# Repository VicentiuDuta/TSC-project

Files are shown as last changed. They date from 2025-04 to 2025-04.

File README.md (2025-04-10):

# OpenBook - E-book Reader

## Descriere generala

OpenBook este un dispozitiv de citit carti electronice (e-book reader) conceput pentru a fi ieftin si open-source.

## Diagrama bloc

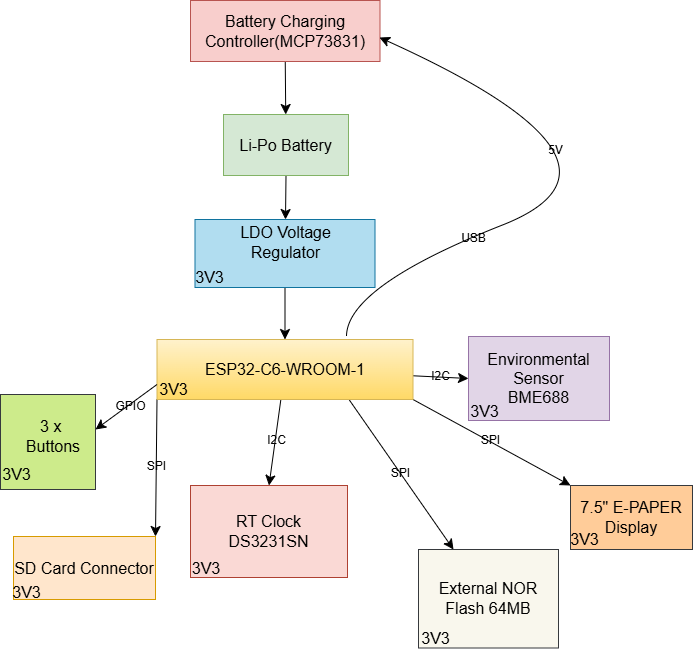
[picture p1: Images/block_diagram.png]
Diagrama bloc


## Bill Of Materials (BOM)
| Componenta | Link | Datasheet |
|---|---|---|
| BD5229G-TR | [Mouser](https://ro.mouser.com/ProductDetail/ROHM-Semiconductor/BD5229G-TR?qs=4kLU8WoGk0vvnhrrYwdszw%3D%3D) | [Datasheet](https://fscdn.rohm.com/en/products/databook/datasheet/ic/power/voltage_detector/bd52xxg-e.pdf)|
| BME688 | [Mouser](https://ro.mouser.com/ProductDetail/Bosch-Sensortec/BME688?qs=IS%252B4QmGtzzqQoVDscqwx3A%3D%3D) | [Datasheet](https://ro.mouser.com/datasheet/2/783/bst_bme688_fl000-2307034.pdf)|
| Bobina | [Mouser](https://ro.mouser.com/ProductDetail/Wurth-Elektronik/744043680?qs=PGXP4M47uW6VkZq%252BkzjrHA%3D%3D) | [Datasheet](https://www.we-online.com/components/products/datasheet/744043680.pdf)|
| Button | [Mouser](https://ro.mouser.com/ProductDetail/CK/KMR221GULCLFS?qs=u2NJ%252B70r0goBXaNk7IrU0Q%3D%3D) |[Datasheet](https://www.ckswitches.com/media/1479/kmr2.pdf)|
| Capacitor 0.1uF / 50V | [Farnell](https://ro.farnell.com/multicomp-pro/mcmlr50v104kx7r/ceramic-capacitor-0-1uf-50v-x7r/dp/1600875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) | [Datasheet](https://www.farnell.com/datasheets/2873577.pdf?_gl=1*x28a2*_gcl_au*MTYwODAzNzc2OC4xNzQzNDM1MjM4)|
| Capacitor 1uF | [Mouser](https://ro.mouser.com/ProductDetail/KEMET/C0402C105K9PACTU?qs=UdQET6xYxVCMExqTDkuPeQ%3D%3D) | [Datasheet](https://ro.mouser.com/datasheet/2/447/KEM_C1006_X5R_SMD-3316465.pdf)|
| Capacitor 1uF / 50V | [Mouser](https://ro.mouser.com/ProductDetail/TDK/C1608X7R1H105K080AB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) | [Datasheet](https://product.tdk.com/system/files/dam/doc/product/capacitor/ceramic/mlcc/catalog/mlcc_commercial_general_en.pdf)|
| Capacitor 4.7uF | [Mouser](https://ro.mouser.com/ProductDetail/KEMET/C0402C475M9PAC7411?qs=cpo3%2FpBou2jRzZxyxJnMGg%3D%3D) | [Datasheet](https://ro.mouser.com/datasheet/2/447/KEM_C1006_X5R_SMD-3316465.pdf)|
| Capacitor 4.7uF / 25V | [Mouser](https://ro.mouser.com/ProductDetail/KYOCERA-AVX/12063C475KAZ2A?qs=%252BdQmOuGyFcG3LdbVp5waMw%3D%3D) | [Datasheet](https://ro.mouser.com/datasheet/2/40/X7RDielectric-2943470.pdf)|
| Capacitor 10uF | [Mouser](https://ro.mouser.com/ProductDetail/KEMET/C0402C106M9PACTU?qs=x4XeXhDQKnp%252Bz0lMlwMC3A%3D%3D) | [Datasheet](https://ro.mouser.com/datasheet/2/447/KEM_C1006_X5R_SMD-3316465.pdf)|
| Capacitor 100nF | [Mouser](https://ro.mouser.com/ProductDetail/KEMET/C0402C104K4RAL?qs=pIZUS6sqCWCaMuP2QVR%2Fog%3D%3D) | [Datasheet](https://ro.mouser.com/datasheet/2/447/KEM_C1018_X7R_SnPb_SMD-3316276.pdf)|
| Capacitor 100uF TANT | [Mouser](https://ro.mouser.com/ProductDetail/KYOCERA-AVX/TAJW107M010RNJ?qs=Wtp%252Bf%2FAeVqIH8v1VxV%252B1Rg%3D%3D) | [Datasheet](https://ro.mouser.com/datasheet/2/40/TAJ-3165264.pdf)|
| Capacitor SUPERCAP | [Mouser](https://ro.mouser.com/ProductDetail/Seiko-Semiconductors/CPH3225A?qs=3etwrb1wR%252BhUOph6lAO7eg%3D%3D) | [Datasheet](https://ro.mouser.com/datasheet/2/360/Seiko_Instruments_MicroBattery_E_20230330_2024Jan_-3561061.pdf)|
| CHG_LED | [CPC](https://cpc.farnell.com/kingbright/kpg-1608zgc/led-smd-0603-grn/dp/SC20796) | [Datasheet](https://www.farnell.com/datasheets/2046349.pdf)|
| DMG2305UX-7 | [Mouser](https://ro.mouser.com/ProductDetail/Diodes-Incorporated/DMG2305UX-7?qs=L1DZKBg7t5F%2FNBHrjfxC%252Bg%3D%3D) | [Datasheet](https://www.diodes.com/assets/Datasheets/DMG2305UX.pdf)|
| DS3231SN# | [Mouser](https://ro.mouser.com/ProductDetail/Analog-Devices-Maxim-Integrated/DS3231SN?qs=1eQvB6Dk1vhUlr8%2FOrV0Fw%3D%3D) | [Datasheet](https://ro.mouser.com/datasheet/2/609/DS3231-3421123.pdf)|
| ESP32-C6-WROOM-1-N8 | [Mouser](https://ro.mouser.com/ProductDetail/Espressif-Systems/ESP32-C6-WROOM-1-N8?qs=8Wlm6%252BaMh8ST02Gmwp74cw%3D%3D) | [Datasheet](https://ro.mouser.com/datasheet/2/891/Espressif_ESP32_C6_WROOM_1__Datasheet_V0_1_PRELIMI-3239987.pdf)|
| FH34SRJ-24S-0.5SH_99_ | [Mouser](https://ro.mouser.com/ProductDetail/Hirose-Connector/FH34SRJ-24S-0.5SH99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) | [Datasheet](https://ro.mouser.com/datasheet/2/185/FH34SRJ_24S_0_5SH_99__CL0580_1255_6_99_2DDrawing_0-1615044.pdf)|
| 112A-TAAR-R03_ATTEND | [LCSC](https://www.lcsc.com/product-detail/SD-Card-Connectors_Attend-Technology-112A-TAAR-R03_C6970445.html) | [Datasheet](https://www.lcsc.com/datasheet/lcsc_datasheet_2411220717_Attend-Technology-112A-TAAR-R03_C6970445.pdf)|
| MAX17048G+T10 | [Mouser](https://ro.mouser.com/ProductDetail/Analog-Devices-Maxim-Integrated/MAX17048G%2bT10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) | [Datasheet](https://ro.mouser.com/datasheet/2/609/MAX17048_MAX17049-3469099.pdf)|
| MBR0530 | [Mouser](https://ro.mouser.com/ProductDetail/onsemi/MBR0530T3G?qs=3JMERSakebpEmdUS6GetdQ%3D%3D) | [Datasheet](https://www.onsemi.com/products/discrete-power-modules/schottky-diodes-schottky-rectifiers/mbr0530t3g)|
| MCP73831 | [Mouser](https://ro.mouser.com/ProductDetail/Microchip-Technology/MCP73831-2ACI-MC?qs=hH%252BOa0VZEiBneYTVdpuVdg%3D%3D) | [Datasheet](https://ro.mouser.com/datasheet/2/268/MCP73831_Family_Data_Sheet_DS20001984H-3441711.pdf)|
| PFMF.050.1 | [Mouser](https://ro.mouser.com/ProductDetail/Schurter/PFMF.050.2?qs=1auRipcfynCums5v1iucSA%3D%3D) | [Datasheet](https://ro.mouser.com/datasheet/2/358/typ_PFMF-1275918.pdf)|
| PGB1010603MR | [Mouser](https://ro.mouser.com/ProductDetail/Littelfuse/PGB1010603MR?qs=gu7KAQ731URLg4GSnNNN7Q%3D%3D) | [Datasheet](https://www.littelfuse.com/assetdocs/pulseguard-esd-suppressors-pgb1-datasheet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)|
| QWIIC_RIGHT_ANGLEA | [Mouser](https://ro.mouser.com/ProductDetail/JST-Commercial/SM04B-SRSS-TBLFSN?qs=cdbOS8ANM9B3FdyA6cNU2A%3D%3D) | [Datasheet](https://ro.mouser.com/datasheet/2/564/eSR_SZ-3476820.pdf)|
| Resistor 0.47 | [Mouser](https://ro.mouser.com/ProductDetail/Vishay-Beyschlag/MCT06030C4700FP500?qs=XsZ9OvPb0dt82KlzjdcMjQ%3D%3D) | [Datasheet](https://www.vishay.com/docs/28705/mcx0x0xpro.pdf)|
| Resistor 2k | [Venkel](https://www.venkel.com/part/CR0402-16W-2002FT) | [Datasheet](https://data.venkel.com/documents/cr-series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.)|
| Resistor 5k1 | [Venkel](https://venkel.com/part/CR0402-10W-5101FT) | [Datasheet](https://data.venkel.com/documents/cr-series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.)|
| Resistor 10K | [DigiKey](https://www.digikey.com/en/products/detail/venkel/CR0402-10W-102JT/12332774) | [Datasheet](https://data.venkel.com/documents/cr-series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.)|
| Resistor 100K | [Venkel](https://venkel.com/part/CR0402-16W-1003FT) | [Datasheet](https://data.venkel.com/documents/cr-series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.)|
| SAMACSYS_PARTS_USB4110-GF-A | [Mouser](https://ro.mouser.com/ProductDetail/GCT/USB4110-GF-A?qs=KUoIvG%2F9IlYiZvIXQjyJeA%3D%3D) | [Datasheet](https://ro.mouser.com/datasheet/2/837/GCT_USB4110_Product_Drawing___20k_cycles-3455479.pdf)|
| SD0805S020S1R0 | [Mouser](https://ro.mouser.com/ProductDetail/KYOCERA-AVX/SD0805S020S1R0?qs=jCA%252BPfw4LHbpkAoSnwrdjw%3D%3D) | [Datasheet](https://ro.mouser.com/datasheet/2/40/schottky-3165252.pdf)|
| SI1308EDL-T1-GE3 | [Mouser](https://ro.mouser.com/ProductDetail/Vishay-Semiconductors/SI1308EDL-T1-GE3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) | [Datasheet](https://www.vishay.com/docs/63399/si1308edl.pdf)|
| USBLC6-2SC6Y | [Mouser](https://ro.mouser.com/ProductDetail/STMicroelectronics/USBLC6-2SC6Y?qs=gNDSiZmRJS%2FOgDexvXkdow%3D%3D) | [Datasheet](https://ro.mouser.com/datasheet/2/389/usblc6_2sc6y-1852505.pdf)|
| W25Q512JVEIQ | [Mouser](https://ro.mouser.com/ProductDetail/Winbond/W25Q512JVEIQ?qs=l7cgNqFNU1jw6svr3at6tA%3D%3D) | [Datasheet](https://ro.mouser.com/datasheet/2/949/Winbond_W25Q512JV_Datasheet-3240039.pdf)|
| XC6220A331MR-G | [Mouser](https://ro.mouser.com/ProductDetail/Torex-Semiconductor/XC6220A331MR-G?qs=AsjdqWjXhJ8ZSWznL1J0gg%3D%3D) | [Datasheet](https://ro.mouser.com/datasheet/2/760/xc6220-3371556.pdf)|

## Descrierea functionalitatii hardware

### Sistem de alimentare si gestionare a energiei

Dispozitivul OpenBook implementeaza un sistem dual de alimentare, functionand atat prin conectorul USB-C cat si prin bateria reincarcabila Li-Po. Modulul MCP73831 gestioneaza procesul de incarcare inteligenta a bateriei, asigurand protectie la supraincarcare si optimizarea ciclurilor de incarcare. Convertorul LDO XC6220A331MR-G stabilizeaza tensiunea la 3.3V pentru toate componentele electronice, asigurand functionarea eficienta a sistemului.

Pentru alimentarea afisajului e-paper, care necesita tensiuni specifice, am proiectat un circuit dedicat bazat pe bobina inductiva 744043680 si diode Schottky pentru generarea si stabilizarea tensiunilor necesare functionarii optime a ecranului.

### Unitatea centrala de procesare

La baza sistemului se afla modulul ESP32-C6-WROOM-1-N8, care integreaza microcontrolerul ESP32-C6 impreuna cu conectivitate wireless WiFi si Bluetooth. Acesta coordoneaza toate operatiunile dispozitivului, de la gestionarea interfetei cu utilizatorul pana la procesarea si afisarea textului. Designul include butoane dedicate pentru reset si boot, facilitand atat utilizarea normala cat si procesele de dezvoltare si depanare.

### Sisteme de conectivitate si interfete

- **Portul USB-C**: Asigura atat alimentarea si incarcarea bateriei cat si transferul de date pentru gestionarea bibliotecii digitale
- **Slotul microSD**: Permite extinderea capacitatii de stocare pentru biblioteci extinse de carti electronice
- **Conectorul FPC cu 24 pini**: Interfata specializata pentru afisajul e-paper de 7.5 inch
- **Conectorul Qwiic/Stemma QT**: Faciliteaza integrarea modulara a senzorilor si perifericelor I2C aditionale

### Subsisteme de stocare si functii auxiliare

- **Memoria flash W25Q512JVEIQ**: Ofera 64MB de spatiu de stocare persistent pentru sistemul de operare si datele utilizatorului
- **Modulul RTC DS3231**: Mentine cronometrarea precisa a timpului real, chiar si cand dispozitivul este oprit, datorita sistemului de backup cu supercapacitor
- **Senzorul ambiental BME688**: Monitorizeaza conditiile de mediu (temperatura, umiditate, presiune atmosferica si calitatea aerului) pentru ajustarea optima a parametrilor de afisare
- **Circuitul integrat MAX17048**: Monitorizeaza cu precizie starea bateriei si ofera utilizatorului informatii despre autonomia ramasa

## Design Log
- Am modificat pozitionarea butoanelor din carcasa pentru a se potrivi cu cele de pe PCB.
- Am aprobat 2 erori DRC de dimenisiune pentru USB, conform enuntului.

## Descrierea pinilor ESP32-C6 utilizati

| Pin ESP32-C6 | Functie | Descriere |
|---|---|---|
| IO0 | INT_RTC | Semnal de intrerupere de la RTC |
| IO1 | 32KHZ | Semnal de ceas de la RTC |
| IO2 | MISO | Comunicatie SPI cu cardul SD|
| IO3 | EPD_BUSY | Semnal ocupat de la e-paper |
| IO4, IO5 | SS_SD, EPD_DC | Selectie card SD si control date/comanda e-paper |
| IO6, IO7 | SCK, MOSI | Clock SPI si date de iesire |
| IO8 | GPIO8 | Pin de uz general |
| IO9 | IO/BOOT | Buton de boot |
| IO10, IO11 | EPD_CS, FLASH_CS | Selectie chip pentru display si memoria flash |
| IO12, IO13 | USB_D-, USB_D+ | Comunicatii USB |
| IO15 | IO/CHANGE | Buton de schimbare pagina |
| IO16 | TX | Transmitere seriala (UART) |
| IO17 | RX | Receptie seriala (UART) |
| IO18 | RTC_RST | Reset pentru RTC |
| IO19 | I2C_PW | Control alimentare pentru perifericele I2C |
| IO20 | EPD_3V3_C | Control alimentare pentru display |
| IO21, IO22 | SDA, SCL | Comunicatii I2C |
| IO23 | EPD_RST | Reset pentru display |
| EN | RESET | Semnal de reset pentru ESP32 |

## Imagini:
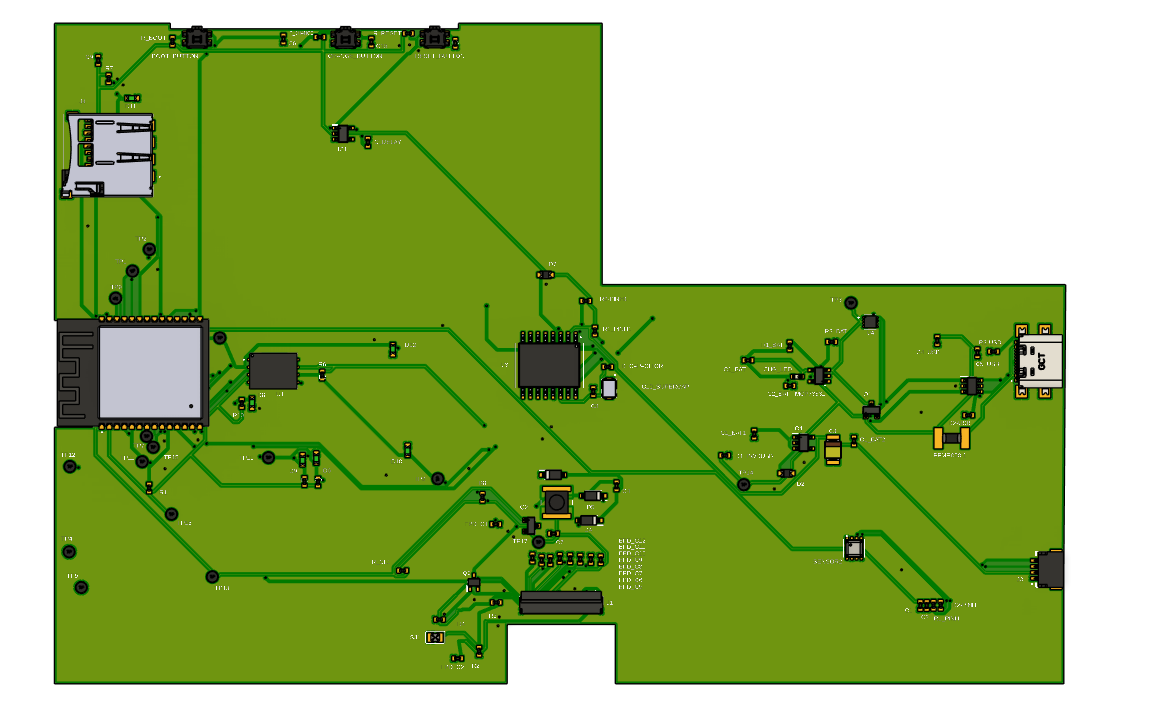
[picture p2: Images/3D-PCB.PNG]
PCB 3D

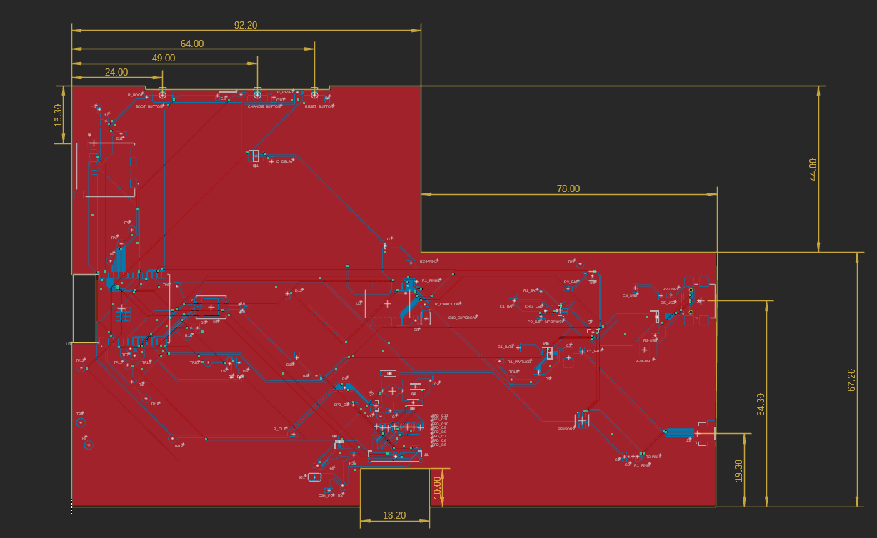
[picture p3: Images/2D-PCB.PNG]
PCB 2D


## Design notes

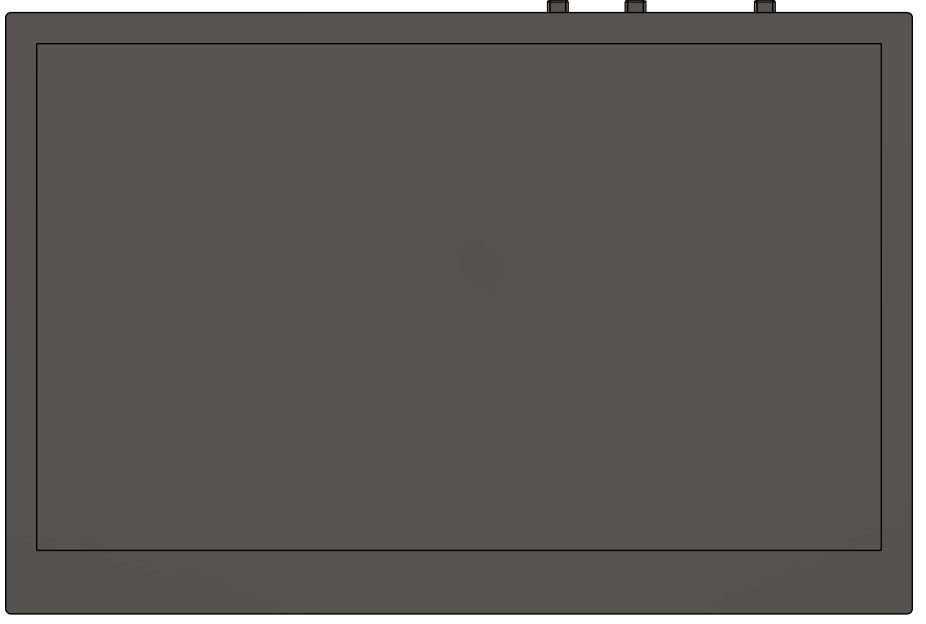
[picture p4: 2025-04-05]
Images/3D-Front.PNG

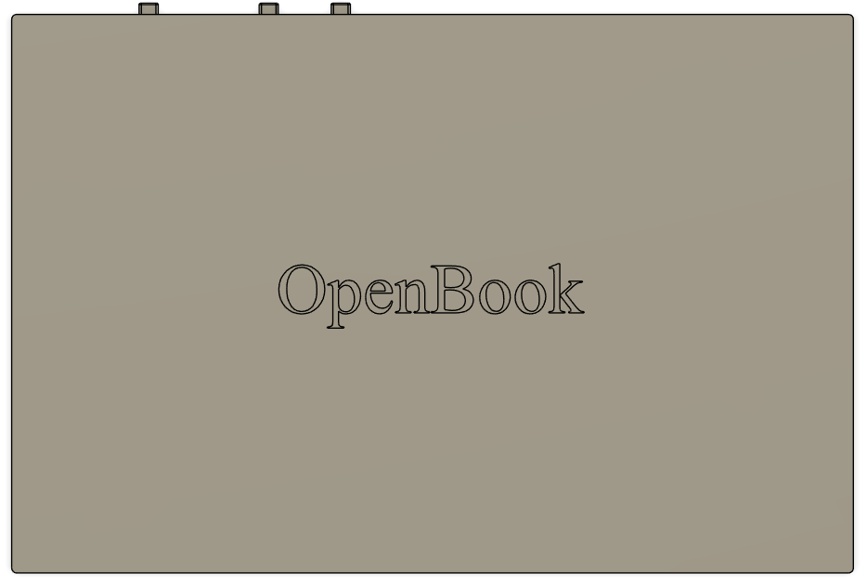
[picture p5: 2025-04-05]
Images/3D-Back.PNG

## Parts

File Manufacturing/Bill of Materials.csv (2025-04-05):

Qty | Value | Device | Package | Parts | Description | ARROW_PART_NUMBER | ARROW_PRICE-STOCK | AVAILABILITY | CENTROID_NOT_SPECIFIED | CHECK_PRICES | COPYRIGHT | DATASHEET | DESCRIPTION | DIGIKEY_DESCRIPTION | DIGIKEY_PART_NUMBER | HEIGHT | LEAD_FREE | MANUFACTURER_NAME | MANUFACTURER_PART_NUMBER | MF | MFR_NAME | MOUSER_PART_NUMBER | MOUSER_PRICE-STOCK | MOUSER_TESTING_PART_NUMBER | MOUSER_TESTING_PRICE-STOCK | MP | MPN | PACKAGE | POPULARITY | PREFIX | PRICE | PROD_ID | PURCHASE-URL | ROHS | SNAPEDA_LINK | SPICEMODEL | SPICEPREFIX | TEMPERATURE_RANGE_HIGH | TEMPERATURE_RANGE_LOW | TP_SIGNAL_NAME | VALUE
1 |  | ADAFRUIT_LEDCHIP-LED0603 | ADAFRUIT_CHIP-LED0603 | CHG_LED | LED
2 |  | ESP32_WROVER_EAGLE-LTSPICE_RR0402 | ESP32_WROVER_EAGLE-LTSPICE_R0402 | R1, R_CHANGE | RESISTOR, European symbol |  |  |  |  |  |  |  |  |  |  |  |  |  |  |  |  |  |  |  |  |  |  |  |  |  |  |  |  |  |  | NONE | R
1 |  | SJ | SJ | SJ1 | SMD solder JUMPER |  |  |  |  |  |  |  |  |  |  |  |  |  |  |  |  |  |  |  |  |  |  |  | 3
1 | 0.1uF/50V | EAGLE-LTSPICE_CC0402 | EAGLE-LTSPICE_C0402 | EPD_C5 | CAPACITOR, European symbol |  |  |  |  |  |  |  |  |  |  |  |  |  |  |  |  |  |  |  |  |  |  |  |  |  |  |  |  |  |  | NONE | C
1 | 0.47 | ESP32_WROVER_EAGLE-LTSPICE_RR0402 | ESP32_WROVER_EAGLE-LTSPICE_R0402 | R3 | RESISTOR, European symbol |  |  |  |  |  |  |  |  |  |  |  |  |  |  |  |  |  |  |  |  |  |  |  |  |  |  |  |  |  |  | NONE | R
1 | 100K | ESP32_WROVER_EAGLE-LTSPICE_RR0402 | ESP32_WROVER_EAGLE-LTSPICE_R0402 | R1_PWRUSB | RESISTOR, European symbol |  |  |  |  |  |  |  |  |  |  |  |  |  |  |  |  |  |  |  |  |  |  |  |  |  |  |  |  |  |  | NONE | R
8 | 100nF | EAGLE-LTSPICE_CC0402 | EAGLE-LTSPICE_C0402 | C1, C2, C4_USB, C6, C8, C9, C10, C_DELAY | CAPACITOR, European symbol |  |  |  |  |  |  |  |  |  |  |  |  |  |  |  |  |  |  |  |  |  |  |  |  |  |  |  |  |  |  | NONE | C
1 | 100uF TANT | RCL_CPOL-EUCT3528 | RCL_CT3528 | C3 | POLARIZED CAPACITOR, European symbol |  |  |  |  |  |  |  |  |  |  |  |  |  |  |  |  |  |  |  |  |  |  |  | 0 |  |  |  |  |  |  |  | C
13 | 10K | ESP32_WROVER_EAGLE-LTSPICE_RR0402 | ESP32_WROVER_EAGLE-LTSPICE_R0402 | R1_PINH, R1_PINH1, R2-PINH, R2-PINH1, R5, R6, R7, R8, R9, R10, R_BOOT, R_CL1, R_RESET | RESISTOR, European symbol |  |  |  |  |  |  |  |  |  |  |  |  |  |  |  |  |  |  |  |  |  |  |  |  |  |  |  |  |  |  | NONE | R
1 | 10k | ESP32_WROVER_EAGLE-LTSPICE_RR0402 | ESP32_WROVER_EAGLE-LTSPICE_R0402 | R4 | RESISTOR, European symbol |  |  |  |  |  |  |  |  |  |  |  |  |  |  |  |  |  |  |  |  |  |  |  |  |  |  |  |  |  |  | NONE | R
1 | 10uF | EAGLE-LTSPICE_CC0402 | EAGLE-LTSPICE_C0402 | C7 | CAPACITOR, European symbol |  |  |  |  |  |  |  |  |  |  |  |  |  |  |  |  |  |  |  |  |  |  |  |  |  |  |  |  |  |  | NONE | C
1 | 112A-TAAR-R03_ATTEND | 112A-TAAR-R03_ATTEND | 112ATAARR03ATTEND | J4 | Micro SD Card Socket, Push-Push Type, Top Mount, SMT, H=1.83mm, 10u |  |  |  |  |  |  |  | Micro SD Card Socket | Push-Push Type | Top Mount | SMT | H=1.83mm | 10u |  |  | 1.9mm |  | ATTEND | 112A-TAAR-R03 ATTEND
1 | 15 | ESP32_WROVER_EAGLE-LTSPICE_RR0402 | ESP32_WROVER_EAGLE-LTSPICE_R0402 | R_CAPACITOR | RESISTOR, European symbol |  |  |  |  |  |  |  |  |  |  |  |  |  |  |  |  |  |  |  |  |  |  |  |  |  |  |  |  |  |  | NONE | R
1 | 1uF | EAGLE-LTSPICE_CC0402 | EAGLE-LTSPICE_C0402 | C5 | CAPACITOR, European symbol |  |  |  |  |  |  |  |  |  |  |  |  |  |  |  |  |  |  |  |  |  |  |  |  |  |  |  |  |  |  | NONE | C
9 | 1uF/50V | EAGLE-LTSPICE_CC0402 | EAGLE-LTSPICE_C0402 | EPD_C1, EPD_C2, EPD_C6, EPD_C7, EPD_C8, EPD_C9, EPD_C10, EPD_C11, EPD_C12 | CAPACITOR, European symbol |  |  |  |  |  |  |  |  |  |  |  |  |  |  |  |  |  |  |  |  |  |  |  |  |  |  |  |  |  |  | NONE | C
1 | 2.2 | ESP32_WROVER_EAGLE-LTSPICE_RR0402 | ESP32_WROVER_EAGLE-LTSPICE_R0402 | R2 | RESISTOR, European symbol |  |  |  |  |  |  |  |  |  |  |  |  |  |  |  |  |  |  |  |  |  |  |  |  |  |  |  |  |  |  | NONE | R
1 | 200 | ESP32_WROVER_EAGLE-LTSPICE_RR0402 | ESP32_WROVER_EAGLE-LTSPICE_R0402 | R1_BAT | RESISTOR, European symbol |  |  |  |  |  |  |  |  |  |  |  |  |  |  |  |  |  |  |  |  |  |  |  |  |  |  |  |  |  |  | NONE | R
2 | 20V/4.2A/52mO/1.4W | ESP32_WROVER_SPARKFUN-DISCRETESEMI_MOSFET_PCH-DMG2305UX-7 | ESP32_WROVER_SPARKFUN-DISCRETESEMI_SOT23-3 | Q1, Q2 | P-channel MOSFETs |  |  |  |  |  |  |  |  |  |  |  |  |  |  |  |  |  |  |  |  |  |  |  |  |  |  | TRAN-14388 |  |  |  |  |  |  |  |  | 20V/4.2A/52mO/1.4W
1 | 2K | ESP32_WROVER_EAGLE-LTSPICE_RR0402 | ESP32_WROVER_EAGLE-LTSPICE_R0402 | R2_BAT | RESISTOR, European symbol |  |  |  |  |  |  |  |  |  |  |  |  |  |  |  |  |  |  |  |  |  |  |  |  |  |  |  |  |  |  | NONE | R
1 | 4.7Uf | EAGLE-LTSPICE_CC0402 | EAGLE-LTSPICE_C0402 | C1_BAT | CAPACITOR, European symbol |  |  |  |  |  |  |  |  |  |  |  |  |  |  |  |  |  |  |  |  |  |  |  |  |  |  |  |  |  |  | NONE | C
4 | 4.7uF | EAGLE-LTSPICE_CC0402 | EAGLE-LTSPICE_C0402 | C1_BAT1, C1_BAT2, C2_BAT, C5_USB | CAPACITOR, European symbol |  |  |  |  |  |  |  |  |  |  |  |  |  |  |  |  |  |  |  |  |  |  |  |  |  |  |  |  |  |  | NONE | C
1 | 4.7uF/25V | EAGLE-LTSPICE_CC0402 | EAGLE-LTSPICE_C0402 | C4 | CAPACITOR, European symbol |  |  |  |  |  |  |  |  |  |  |  |  |  |  |  |  |  |  |  |  |  |  |  |  |  |  |  |  |  |  | NONE | C
2 | 5K1 | ESP32_WROVER_EAGLE-LTSPICE_RR0402 | ESP32_WROVER_EAGLE-LTSPICE_R0402 | R2-USB, R2-USB1 | RESISTOR, European symbol |  |  |  |  |  |  |  |  |  |  |  |  |  |  |  |  |  |  |  |  |  |  |  |  |  |  |  |  |  |  | NONE | R
1 | 744043680IND_4828-WE-TPC_WRE | 744043680IND_4828-WE-TPC_WRE | IND_4828-WE-TPC_WRE | L1 |  |  |  |  |  |  | Copyright (C) 2024 Ultra Librarian. All rights reserved. |  |  |  |  |  |  |  | 744043680 |  | Wurth Electronics
1 | BD5229G-TR | BD5229G-TR | SOT95P280X125-5N | IC1 | Voltage Detector with Adjustable Delay Time: CMOS processes are utilized to develop high precision, low current consumption CMOS reset ICs that allow arbitrary setting of the delay time. The extensive lineup includes both Nch Open Drain and CMOS output types in a wide range of detection voltages (from 2.3V to 6.0V, in 0.1V steps), enabling selection of the ideal solution based on customer requirements. In addition, the entire series is of course both lead-free and RoHS-compliant. |  |  |  |  |  |  |  | Voltage Detector with Adjustable Delay Time: CMOS processes are utilized to develop high precision | low current consumption CMOS reset ICs that allow arbitrary setting of the delay time. The extensive lineup includes both Nch Open Drain and CMOS output types in a wide range of detection voltages (from 2.3V to 6.0V | in 0.1V steps) | enabling selection of the ideal solution based on customer requirements. In addition | the entire series is of course both lead-free and RoHS-compliant. |  |  | 1.25mm |  | ROHM Semiconductor | BD5229G-TR |  |  | 755-BD5229G-TR | https://www.mouser.co.uk/ProductDetail/ROHM-Semiconductor/BD5229G-TR?qs=4kLU8WoGk0vvnhrrYwdszw%3D%3D
3 | BUTTON_CUSYOMV1 | BUTTON_CUSYOMV1 | MYBUTTON | BOOT_BUTTON, CHANGE_BUTTON, RESET_BUTTON
1 | CPH3225A | CPH3225A | CAPCP3225X100N | C10_SUPERCAP | Cap 0.011F 3.3V 1210 Flat Check availability |  |  | Not in stock |  | https://www.snapeda.com/parts/CPH3225A/Seiko+Instruments/view-part/?ref=eda |  |  | 11 mF (EDLC) Supercapacitor 3.3 V 1210 (3225 Metric) - - |  |  |  |  |  |  | Seiko Instruments |  |  |  |  |  | CPH3225A |  | 1210 Seiko |  |  | None |  | https://www.snapeda.com/api/url_track_click_mouser/?unipart_id=562593&manufacturer=Seiko Instruments&part_name=CPH3225A&search_term=None |  | https://www.snapeda.com/parts/CPH3225A/Seiko+Instruments/view-part/?ref=snap
1 | DS3231SN# | DS3231SN# | SOIC127P1032X265-16N | U3 | Real Time Clock Serial 16-Pin SOIC W T/R Check availability |  |  | In Stock |  | https://www.snapeda.com/parts/DS3231SN%23/Analog+Devices/view-part/?ref=eda |  |  | Extremely Accurate I²C-Integrated RTC/TCXO/Crystal |  |  |  |  |  |  | Analog Devices |  |  |  |  |  | DS3231SN# |  | SOIC-16 Maxim |  |  | None |  | https://www.snapeda.com/api/url_track_click_mouser/?unipart_id=99048&manufacturer=Analog Devices&part_name=DS3231SN#&search_term=None |  | https://www.snapeda.com/parts/DS3231SN%23/Analog+Devices/view-part/?ref=snap
1 | ESP32-C6-WROOM-1-N8 | ESP32-C6-WROOM-1-N8 | XCVR_ESP32-C6-WROOM-1-N8 | U2 | Check availability |  |  | In Stock |  | https://www.snapeda.com/parts/ESP32-C6-WROOM-1-N8/Espressif+Systems/view-part/?ref=eda |  |  | Multiprotocol Modules ESP32-C6 module | Wi-Fi 6 in 2.4 GHz band | Bluetooth 5 | Zigbee 3.0 and Thread. ESP34-WROOM Compatible - ENGINEERING SAMPLE |  |  |  |  |  |  | Espressif Systems |  |  |  |  |  | ESP32-C6-WROOM-1-N8 |  | None |  |  | None |  |  |  | https://www.snapeda.com/parts/ESP32-C6-WROOM-1-N8/Espressif+Systems/view-part/?ref=snap
1 | ESP32C6_VARISTORCN1812 | ESP32C6_VARISTORCN1812 | ESP32C6_VARISTOR_CT/CN1812 | PFMF.050.1 | VARISTOR |  |  |  |  |  |  |  |  |  |  |  |  |  |  |  |  |  |  |  |  |  |  |  | 0
2 | ESP32_WROVER_AVX---SD0805S020S1R0_AVX_SD0805S020S1R0_0_0AVX_SD0805S020S1R0_0_0 | ESP32_WROVER_AVX---SD0805S020S1R0_AVX_SD0805S020S1R0_0_0AVX_SD0805S020S1R0_0_0 | ESP32_WROVER_AVX---SD0805S020S1R0_AVX_SD0805S020S1R0_0 | D2, D7 | Schottky Barrier Rectifier Diode |  |  |  | No |  |  | http://datasheets.avx.com/schottky.pdf |  | DIODE SCHOTTKY 20V 1A 0805 | 478-7800-1-ND |  | yes |  |  | AVX |  | 581-SD0805S020S1R0 |  |  |  |  |  | 0805 (2012 metric) |  | D |  |  |  | yes |  |  |  | +125°C | -55°C
1 | ESP32_WROVER_BME680_BME680 | ESP32_WROVER_BME680_BME680 | ESP32_WROVER_BME680_PSON80P300X300X100-8N | SENSOR2 | Integrated Environmental Unit |  |  | Unavailable |  |  |  |  | Integrated Environmental Unit |  |  |  |  |  |  | Bosch Sensortec |  |  |  |  |  | BME680 |  | LGA-8 Bosch Tools |  |  | None
1 | ESP32_WROVER_SPARKFUN-IC-POWER_MCP73831 | ESP32_WROVER_SPARKFUN-IC-POWER_MCP73831 | ESP32_WROVER_SPARKFUN-IC-POWER_SOT23-5 | MCP73831 | MCP73831T Li-Ion, Li-Pol Controller |  |  |  |  |  |  |  |  |  |  |  |  |  |  |  |  |  |  |  |  |  |  |  |  |  |  | IC-09995
1 | FH34SRJ-24S-0.5SH_99_ | FH34SRJ-24S-0.5SH_99_ | FH34SRJ24S05SH99 | J1 | (0.50mm) Surface Mount, Right Angle |  |  |  |  |  |  |  | 24 Position FFC | FPC Connector Contacts | (0.50mm) Surface Mount | Right Angle |  |  | 1.1mm |  | Hirose | FH34SRJ-24S-0.5SH(99) |  |  | 798-FH34SRJ24S05SH99 | https://www.mouser.co.uk/ProductDetail/Hirose-Connector/FH34SRJ-24S-0.5SH99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
1 | MAX17048G+T10 | MAX17048G+T10 | SON50P200X200X80-9N | U4 | Check availability |  |  | In Stock |  | https://www.snapeda.com/parts/MAX17048G+T10/Analog+Devices/view-part/?ref=eda |  |  | 3µA 1-Cell/2-Cell Fuel Gauge with ModelGauge |  |  |  |  |  |  | Analog Devices |  |  |  |  |  | MAX17048G+T10 |  | TDFN-8 Maxim |  |  | None |  | https://www.snapeda.com/api/url_track_click_mouser/?unipart_id=329239&manufacturer=Analog Devices&part_name=MAX17048G+T10&search_term=None |  | https://www.snapeda.com/parts/MAX17048G+T10/Analog+Devices/view-part/?ref=snap
3 | MBR0530 | MBR0530 | SOD3716X135N | D3, D4, D5 | ON SEMICONDUCTOR - MBR0530 - DIODE, SCHOTTKY, 0.5A, 30V, SOD-123 |  |  | In Stock |  | https://www.snapeda.com/parts/MBR0530/Onsemi/view-part/?ref=eda |  |  | Diode Schottky 30 V 500mA Surface Mount SOD-123 |  |  |  |  |  |  | ON Semiconductor |  |  |  |  |  | MBR0530 |  | SOD-123-2 ON Semiconductor |  |  | None |  | https://www.snapeda.com/api/url_track_click_mouser/?unipart_id=179458&manufacturer=ON Semiconductor&part_name=MBR0530&search_term=None |  | https://www.snapeda.com/parts/MBR0530/Onsemi/view-part/?ref=snap
6 | PGB1010603MR | PGB1010603MR | DIOC1608X36N | D6, D8, D9, D10, D11, D12 | Check availability |  |  | In Stock |  | https://www.snapeda.com/parts/PGB1010603MR/Littelfuse/view-part/?ref=eda |  |  | 150V (Typ) Clamp - Ipp Tvs Diode Surface Mount 0603 (1608 Metric) |  |  |  |  |  |  | Littelfuse Inc. |  |  |  |  |  | PGB1010603MR |  | 0603 Littelfuse Inc. |  |  | None |  | https://www.snapeda.com/api/url_track_click_mouser/?unipart_id=5659453&manufacturer=Littelfuse Inc.&part_name=PGB1010603MR&search_term=None |  | https://www.snapeda.com/parts/PGB1010603MR/Littelfuse/view-part/?ref=snap
1 | QWIIC_RIGHT_ANGLE | QWIIC_CONNECTORJS-1MM | JST04_1MM_RA | J3 | SparkFun I2C Standard Qwiic Connector |  |  |  |  |  |  |  |  |  |  |  |  |  |  |  |  |  |  |  |  |  |  |  |  |  |  | CONN-13694 |  |  |  |  |  |  |  |  | QWIIC_RIGHT_ANGLE
1 | SAMACSYS_PARTS_USB4110-GF-A | SAMACSYS_PARTS_USB4110-GF-A | SAMACSYS_PARTS_USB4110GFA | J2 | CONN USB 2.0 TYPE-C R/A SMT |  |  |  |  |  |  |  | CONN USB 2.0 TYPE-C R/A SMT |  |  | 3.26mm |  | GCT (GLOBAL CONNECTOR TECHNOLOGY) | USB4110-GF-A |  |  | 640-USB4110-GF-A | https://www.mouser.co.uk/ProductDetail/GCT/USB4110-GF-A?qs=KUoIvG%2F9IlYiZvIXQjyJeA%3D%3D
1 | SI1308EDL-T1-GE3 | SI1308EDL-T1-GE3 | SOT65P210X110-3N | Q3 | MOSFET N-Ch 30V 1.5A TrenchFET SC70 Vishay Si1308EDL-T1-GE3 N-channel MOSFET Transistor, 1.5 A, 30 V, 3-Pin SC-70 |  |  | In Stock |  | https://www.snapeda.com/parts/SI1308EDL-T1-GE3/Vishay+Siliconix/view-part/?ref=eda |  |  | Si1308EDL-T1-GE3 N-channel MOSFET Transistor | 1.5 A | 30 V | 3-Pin SC-70 | Siliconix / Vishay SI1308EDL-T1-GE3 |  |  |  |  |  |  | Vishay Siliconix |  |  |  |  |  | SI1308EDL-T1-GE3 |  | SOT-323 Vishay Semiconductor |  |  | None |  | https://www.snapeda.com/api/url_track_click_mouser/?unipart_id=274603&manufacturer=Vishay Siliconix&part_name=SI1308EDL-T1-GE3&search_term=None |  | https://www.snapeda.com/parts/SI1308EDL-T1-GE3/Vishay+Siliconix/view-part/?ref=snap
17 | TPTP20R | TPTP20R | TP20R | TP1, TP2, TP3, TP4, TP5, TP6, TP7, TP8, TP9, TP10, TP11, TP12, TP13, TP14, TP15, TP16, TP17 | Test pad |  |  |  |  |  |  |  |  |  |  |  |  |  |  |  |  |  |  |  |  |  |  |  | 2
1 | USBLC6-2SC6Y | USBLC6-2SC6Y | SOT95P280X145-6N | D1 | Low Cap. ESD Protection Auto SOT-23-6 STMicroelectronics USBLC6-2SC6Y, Dual Uni-Directional TVS Diode Array, 6-Pin SOT-23 |  |  | In Stock |  | https://www.snapeda.com/parts/USBLC6-2SC6Y/STMicroelectronics/view-part/?ref=eda |  |  | 17V Clamp 5A (8/20µs) Ipp Tvs Diode Surface Mount SOT-23-6 |  |  |  |  |  |  | STMicroelectronics |  |  |  |  |  | USBLC6-2SC6Y |  | SOT-23-6 STMicroelectronics |  |  | None |  |  |  | https://www.snapeda.com/parts/USBLC6-2SC6Y/STMicroelectronics/view-part/?ref=snap
1 | W25Q512JVEIQ | W25Q512JVEIQ | SON127P600X800X80-9N | U1 | Check availability |  |  | In Stock |  | https://www.snapeda.com/parts/W25Q512JVEIQ/Winbond+Electronics/view-part/?ref=eda |  |  | FLASH - NOR Memory IC 512Mb (64M x 8) SPI - Quad I/O 133 MHz 8-WSON (8x6) |  |  |  |  |  |  | Winbond Electronics |  |  |  |  |  | W25Q512JVEIQ |  | Package |  |  | None |  |  |  | https://www.snapeda.com/parts/W25Q512JVEIQ/Winbond+Electronics/view-part/?ref=snap
1 | XC6220A331MR-G | XC6220A331MR-G | SOT95P280X120-5N | IC4 | LDO Voltage Regulators |  |  |  |  |  |  |  | LDO Voltage Regulators |  |  | 1.2mm |  | Torex | XC6220A331MR-G |  |  | 865-XC6220A331MR-G | https://www.mouser.co.uk/ProductDetail/Torex-Semiconductor/XC6220A331MR-G?qs=AsjdqWjXhJ8ZSWznL1J0gg%3D%3D

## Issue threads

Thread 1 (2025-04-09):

Probleme structură: gerbers.zip

MihailaStefanAlexandru, 2025-04-09:
În gerbers.zip trebuie să se găsească fișiere GBR, de preferat la finalul soluționării tuturor issue-urilor legate de schematic și PCB. (https://help.autodesk.com/view/fusion360/ENU/?guid=ECD-CAM-SUPPORT-CPT).

Doar fișierele .gbr în .zip.

În actuala arhivă apare o întreagă ierahie cu fișiere care nu sunt toate de format .gbr.

Ar fi bine dacă le-ai genera din nou la final de tot după ce ai făcut eventuale schimbări și/sau modificări pentru a se genera și pentru aceste schimbări.

Closed 2025-04-14.

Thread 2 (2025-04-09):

Schematic

MihailaStefanAlexandru, 2025-04-09:
Unități de măsură lipsă sau eronate ale unor componentete din schemă (nu cele din schema din documentație) (ESP32 C6)

VicentiuDuta, 2025-04-09:
Am rezolvat problema.

Closed 2025-04-09.

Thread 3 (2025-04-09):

Schematic

MihailaStefanAlexandru, 2025-04-09:
În cazul câtorva componente numele nu este lizibil sau confuz (nume multiple în vecinătatea pieselor).

- [] E Paper Drive Circuit
- [] Environmental Sensor BME688
- [] USB C Connector & ESD protection

VicentiuDuta, 2025-04-09:
Am rezolvat problema.

Closed 2025-04-09.

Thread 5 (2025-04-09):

Schematic

MihailaStefanAlexandru, 2025-04-09:
Nerezolvare erori schematic (CAD ERC 100% clean) sau omitere menționare justificare pentru acceptarea acestora în Readme.

CAD ERC:
Apare la tools (fereastra de unde se selectează componentele) la rubrica errors (ca la PCB) dai refresh și apar la warnings.

Ori le rezolvi ori le scrii în Readme de ce le-ai acceptat.

Closed 2025-04-10.

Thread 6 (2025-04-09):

PCB

MihailaStefanAlexandru, 2025-04-09:
Lipsă motivare pentru acceptarea erorilor din cadrul DRC-urilor.

S-au menționat acestea dar nu s-a argumentat decizia asupra lor.

”Am aprobat 2 erori DRC de dimenisiune pentru USB.” (de ce?)

De pe ocw: ”pașii de implementare, probleme, decizii luate (ex: “am acceptat aceste erori de overlap pentru că…”)

VicentiuDuta, 2025-04-09:
Am rezolvat problema.

Closed 2025-04-09.

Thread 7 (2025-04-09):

PCB

MihailaStefanAlexandru, 2025-04-09:
Poziționare diferită a componentelor în PCB comparativ cu deskassistent_drawing.pdf.

Nu este menționată această schimbare și dacă aduce implicații nedorite sau nu asupra funcționării dispozitivului.

Sunt poziționate câteva componente care nu sunt pe pozițiile din documentul pdf din ocw.

Trebuie menționat și argumentat de ce s-a luat această decizie.

ocw: „pașii de implementare, probleme, decizii luate (ex: “am acceptat aceste erori de overlap pentru că…”)”

VicentiuDuta, 2025-04-09:
Am pozitionat componentele diferit pentru a reduce numarul de vias-uri.

Closed 2025-04-09.

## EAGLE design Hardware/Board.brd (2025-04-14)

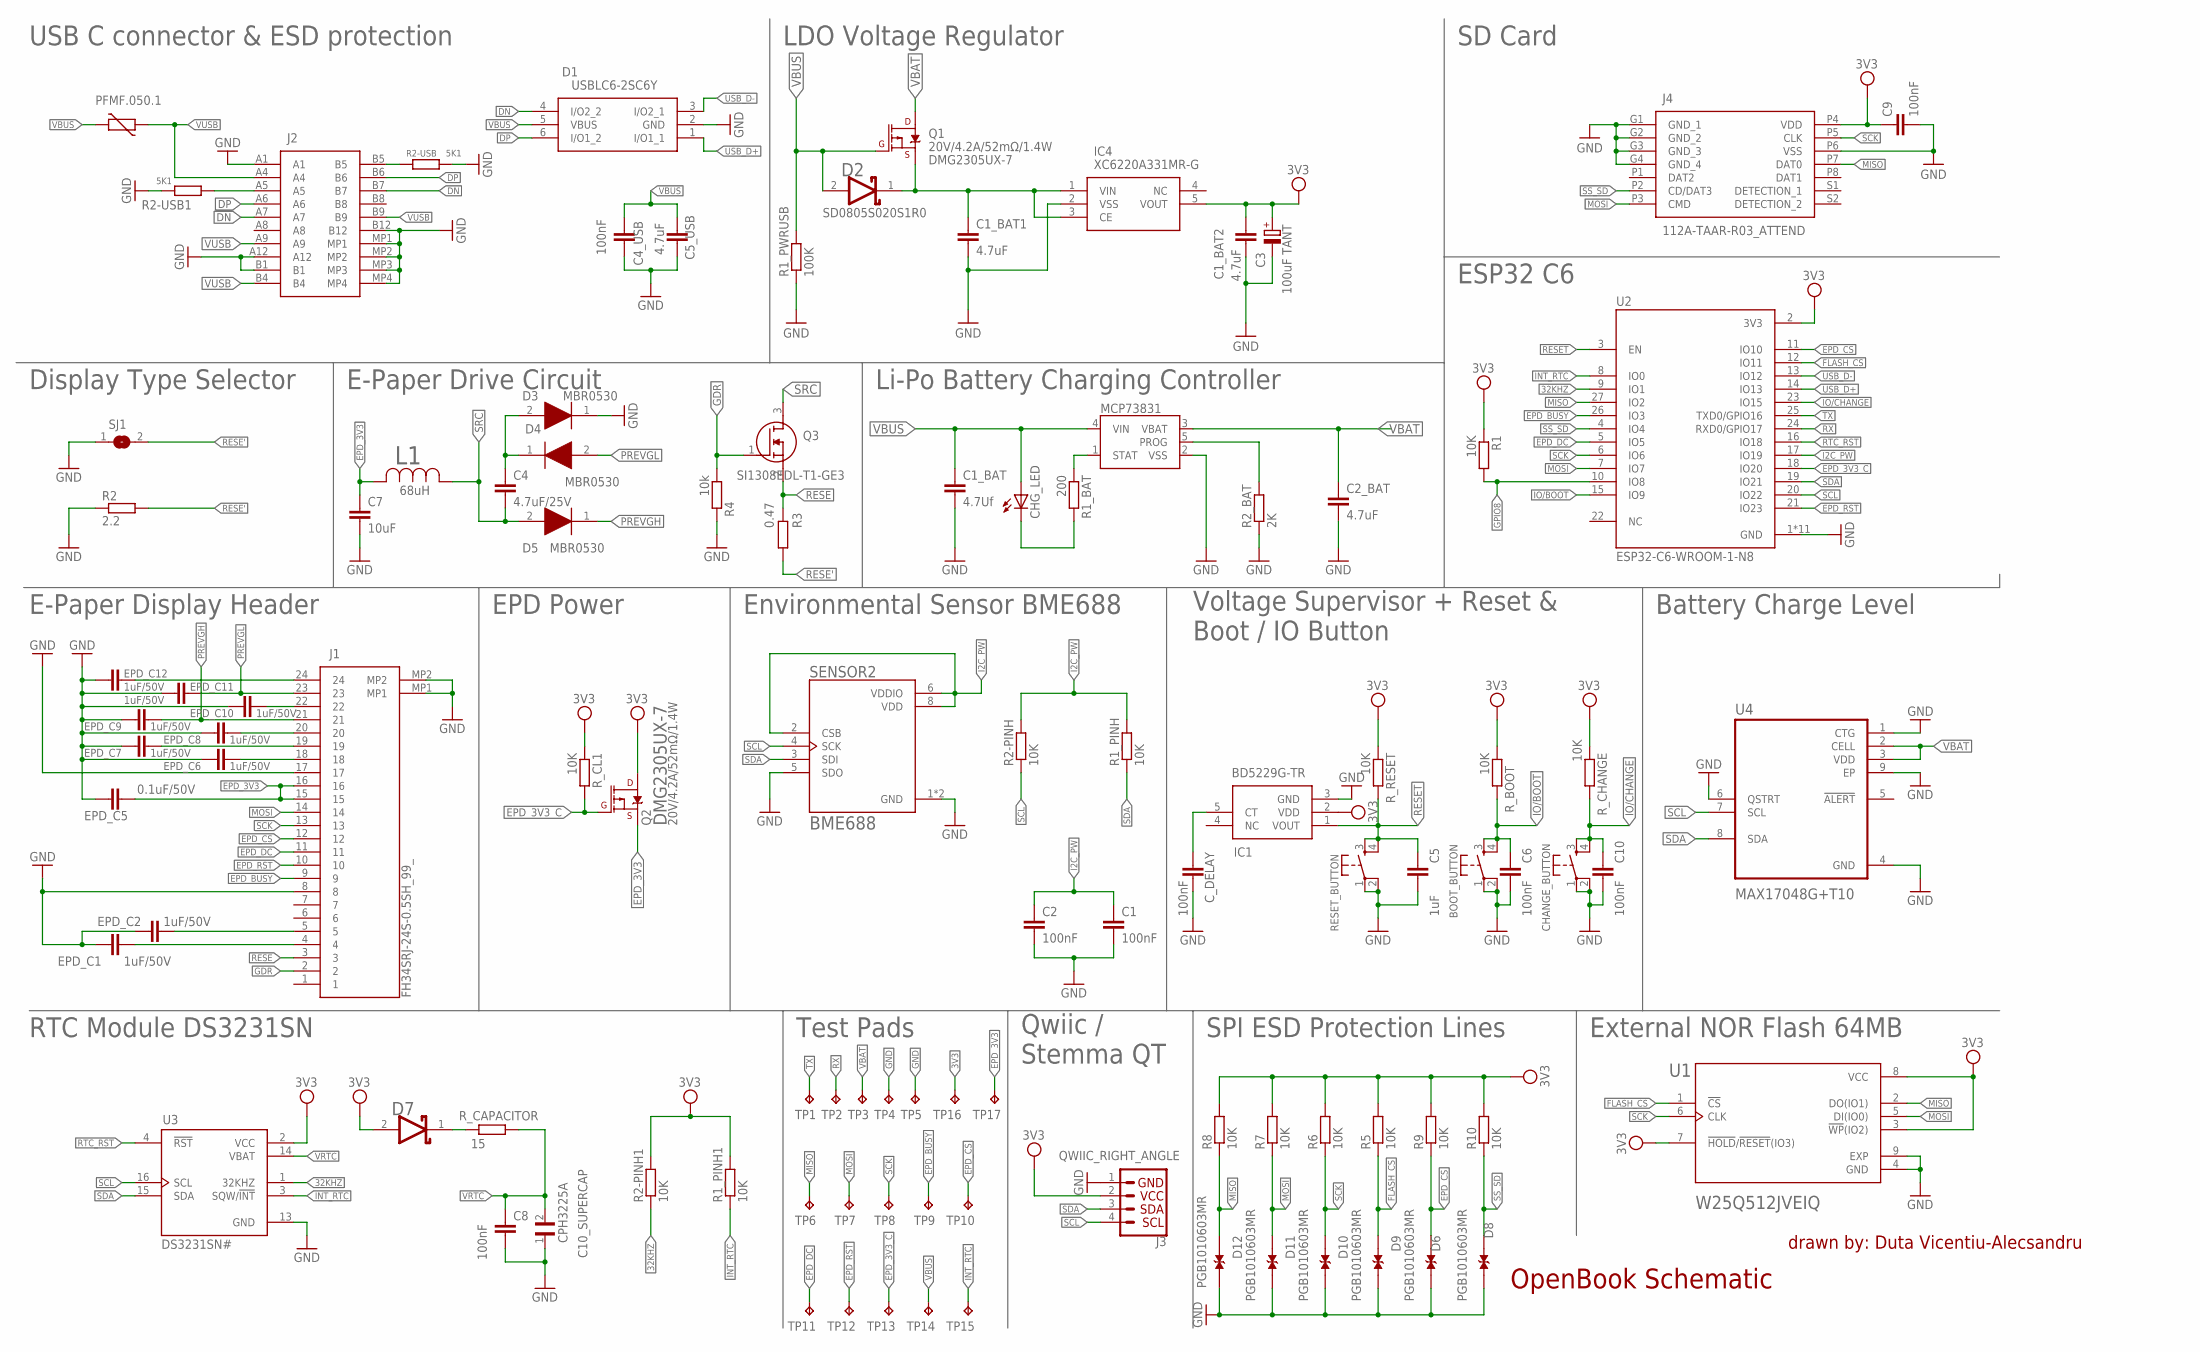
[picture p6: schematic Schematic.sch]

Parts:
BOOT_BUTTON: BUTTON_CUSYOMV1; MYBUTTON
C1, C2, C4_USB, C6, C8, C9, C10: 100nF; EAGLE-LTSPICE_C0402
C1_BAT: 4.7Uf; EAGLE-LTSPICE_C0402
C1_BAT1, C1_BAT2, C2_BAT, C5_USB: 4.7uF; EAGLE-LTSPICE_C0402
C3: 100uF TANT; RCL_CT3528
C4: 4.7uF/25V; EAGLE-LTSPICE_C0402
C5: 1uF; EAGLE-LTSPICE_C0402
C7: 10uF; EAGLE-LTSPICE_C0402
C10_SUPERCAP: CPH3225A; CAPCP3225X100N
CHANGE_BUTTON: BUTTON_CUSYOMV1; MYBUTTON
CHG_LED: ADAFRUIT_LEDCHIP-LED0603; ADAFRUIT_CHIP-LED0603
C_DELAY: 100nF; EAGLE-LTSPICE_C0402
D1: USBLC6-2SC6Y; SOT95P280X145-6N
D2, D7: ESP32_WROVER_AVX---SD0805S020S1R0_AVX_SD0805S020S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; ESP32_WROVER_AVX---SD0805S020S1R0_AVX_SD0805S020S1R0_0
D3, D4, D5: MBR0530; SOD3716X135N
D6, D8, D9, D10, D11, D12: PGB1010603MR; DIOC1608X36N
EPD_C1, EPD_C2, EPD_C6, EPD_C7, EPD_C8, EPD_C9, EPD_C10, EPD_C11, EPD_C12: 1uF/50V; EAGLE-LTSPICE_C0402
EPD_C5: 0.1uF/50V; EAGLE-LTSPICE_C0402
IC1: BD5229G-TR; SOT95P280X125-5N
IC4: XC6220A331MR-G; SOT95P280X120-5N
J1: FH34SRJ-24S-0.5SH_99_; FH34SRJ24S05SH99
J2: SAMACSYS_PARTS_USB4110-GF-A; SAMACSYS_PARTS_USB4110GFA
J3: QWIIC_RIGHT_ANGLE; JST04_1MM_RA
J4: 112A-TAAR-R03_ATTEND; 112ATAARR03ATTEND
L1: 744043680IND_4828-WE-TPC_WRE; IND_4828-WE-TPC_WRE
MCP73831: ESP32_WROVER_SPARKFUN-IC-POWER_MCP73831; ESP32_WROVER_SPARKFUN-IC-POWER_SOT23-5
PFMF.050.1: ESP32C6_VARISTORCN1812; ESP32C6_VARISTOR_CT/CN1812
Q1, Q2: 20V/4.2A/52mΩ/1.4W; ESP32_WROVER_SPARKFUN-DISCRETESEMI_SOT23-3
Q3: SI1308EDL-T1-GE3; SOT65P210X110-3N
R1, R1_PINH, R1_PINH1, R2-PINH, R2-PINH1, R5, R6, R7, R8, R9, R10: 10K; ESP32_WROVER_EAGLE-LTSPICE_R0402
R1_BAT: 200; ESP32_WROVER_EAGLE-LTSPICE_R0402
R1_PWRUSB: 100K; ESP32_WROVER_EAGLE-LTSPICE_R0402
R2: 2.2; ESP32_WROVER_EAGLE-LTSPICE_R0402
R2-USB, R2-USB1: 5K1; ESP32_WROVER_EAGLE-LTSPICE_R0402
R2_BAT: 2K; ESP32_WROVER_EAGLE-LTSPICE_R0402
R3: 0.47; ESP32_WROVER_EAGLE-LTSPICE_R0402
R4: 10k; ESP32_WROVER_EAGLE-LTSPICE_R0402
RESET_BUTTON: BUTTON_CUSYOMV1; MYBUTTON
R_BOOT: 10K; ESP32_WROVER_EAGLE-LTSPICE_R0402
R_CAPACITOR: 15; ESP32_WROVER_EAGLE-LTSPICE_R0402
R_CHANGE: 10K; ESP32_WROVER_EAGLE-LTSPICE_R0402
R_CL1: 10K; ESP32_WROVER_EAGLE-LTSPICE_R0402
R_RESET: 10K; ESP32_WROVER_EAGLE-LTSPICE_R0402
SENSOR2: ESP32_WROVER_BME680_BME680; ESP32_WROVER_BME680_PSON80P300X300X100-8N
SJ1: SJ
TP1, TP2, TP3, TP4, TP5, TP6, TP7, TP8, TP9, TP10, TP11, TP12, TP13, TP14, TP15, TP16, TP17: TPTP20R; TP20R
U1: W25Q512JVEIQ; SON127P600X800X80-9N
U2: ESP32-C6-WROOM-1-N8; XCVR_ESP32-C6-WROOM-1-N8
U3: DS3231SN#; SOIC127P1032X265-16N
U4: MAX17048G+T10; SON50P200X200X80-9N

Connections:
3V3: C1_BAT2.1, C3.+, C9.1, D7.2 (ANODE), IC1.2 (VDD), IC4.5 (VOUT), J3.2, J4.P4 (VDD), Q2.3 (D), R1.1, R1_PINH1.2, R2-PINH1.2, R5.2, R6.2, R7.2, R8.2, R9.2, R10.2, R_BOOT.1, R_CHANGE.1, R_CL1.1, R_RESET.1, TP16.TP, U1.3 (!WP!(IO2)), U1.7 (!HOLD!/!RESET!(IO3)), U1.8 (VCC), U2.2 (3V3), U3.2 (VCC)
32KHZ: R2-PINH1.1, U2.9 (IO1), U3.1 (32KHZ)
DN: D1.4 (I/O2_2), J2.A7, J2.B7
DP: D1.6 (I/O1_2), J2.A6, J2.B6
EPD_3V3: C7.1, EPD_C5.1, J1.15, J1.16, L1.2, Q2.2 (S), TP17.TP
EPD_3V3_C: Q2.1 (G), R_CL1.2, TP13.TP, U2.18 (IO20)
EPD_BUSY: J1.9, TP9.TP, U2.26 (IO3)
EPD_CS: D6.1, J1.12, R9.1, TP10.TP, U2.11 (IO10)
EPD_DC: J1.11, TP11.TP, U2.5 (IO5)
EPD_RST: J1.10, TP12.TP, U2.21 (IO23)
FLASH_CS: D9.1, R5.1, U1.1 (!CS), U2.12 (IO11)
GDR: J1.2, Q3.1 (G), R4.1
GND: BOOT_BUTTON.1, BOOT_BUTTON.2, C1.2, C1_BAT.2, C1_BAT1.2, C1_BAT2.2, C2.2, C2_BAT.2, C3.-, C4_USB.2, C5.2, C5_USB.2, C6.2, C7.2, C8.2, C9.2, C10.2, C10_SUPERCAP.1, CHANGE_BUTTON.1, CHANGE_BUTTON.2, C_DELAY.2, D1.2 (GND), D3.1 (K), D6.2, D8.2, D9.2, D10.2, D11.2, D12.2, EPD_C1.2, EPD_C2.2, EPD_C5.2, EPD_C6.2, EPD_C7.2, EPD_C8.2, EPD_C9.2, EPD_C10.2, EPD_C11.2, EPD_C12.2, IC1.3 (GND), IC4.2 (VSS), J1.8, J1.17, J1.MP1, J1.MP2, J2.A1, J2.A12, J2.B1, J2.B12, J2.MP1, J2.MP2, J2.MP3, J2.MP4, J3.1, J4.G1 (GND_1), J4.G2 (GND_2), J4.G3 (GND_3), J4.G4 (GND_4), J4.P6 (VSS), MCP73831.2 (VSS), R1_PWRUSB.1, R2.1, R2-USB.2, R2-USB1.1, R2_BAT.1, R4.2, RESET_BUTTON.1, RESET_BUTTON.2, SENSOR2.1 (GND), SENSOR2.5 (SDO), SENSOR2.7 (GND), SJ1.1, TP4.TP, TP5.TP, U1.4 (GND), U1.9 (EXP), U2.1 (GND), U2.28 (GND), U2.29_1 (GND), U2.29_2 (GND), U2.29_3 (GND), U2.29_4 (GND), U2.29_5 (GND), U2.29_6 (GND), U2.29_7 (GND), U2.29_8 (GND), U2.29_9 (GND), U3.13 (GND), U4.1 (CTG), U4.4 (GND), U4.6 (QSTRT), U4.9 (EP)
GPIO8: R1.2, U2.10 (IO8)
I2C_PW: C1.1, C2.1, R1_PINH.2, R2-PINH.2, SENSOR2.2 (CSB), SENSOR2.6 (VDDIO), SENSOR2.8 (VDD), U2.17 (IO19)
INT_RTC: R1_PINH1.1, TP15.TP, U2.8 (IO0), U3.3 (SQW/!INT)
IO/BOOT: BOOT_BUTTON.3, BOOT_BUTTON.4, C6.1, R_BOOT.2, U2.15 (IO9)
IO/CHANGE: C10.1, CHANGE_BUTTON.3, CHANGE_BUTTON.4, R_CHANGE.2, U2.23 (IO15)
MISO: D12.1, J4.P7 (DAT0), R8.1, TP6.TP, U1.2 (DO(IO1)), U2.27 (IO2)
MOSI: D11.1, J1.14, J4.P3 (CMD), R7.1, TP7.TP, U1.5 (DI(IO0)), U2.7 (IO7)
unnamed: J2.B5, R2-USB.1
unnamed: MCP73831.1 (STAT), R1_BAT.1
unnamed: C1_BAT1.1, D2.1 (CATHODE), IC4.1 (VIN), IC4.3 (CE), Q1.2 (S)
unnamed: MCP73831.5 (PROG), R2_BAT.2
unnamed: C4.1, D3.2 (A), D4.1 (K)
unnamed: CHG_LED.C, R1_BAT.2
unnamed: C_DELAY.1, IC1.5 (CT)
unnamed: EPD_C2.1, J1.5
unnamed: EPD_C1.1, J1.4
unnamed: EPD_C6.1, J1.18
unnamed: J2.A5, R2-USB1.2
unnamed: EPD_C8.1, J1.20
unnamed: EPD_C7.1, J1.19
unnamed: EPD_C10.1, J1.22
unnamed: EPD_C12.1, J1.24
unnamed: D7.1 (CATHODE), R_CAPACITOR.2
PREVGH: D5.1 (K), EPD_C9.1, J1.21
PREVGL: D4.2 (A), EPD_C11.1, J1.23
RESE: J1.3, Q3.2 (S), R3.2
RESE': R2.2, R3.1, SJ1.2
RESET: C5.1, IC1.1 (VOUT), RESET_BUTTON.3, RESET_BUTTON.4, R_RESET.2, U2.3 (EN)
RTC_RST: U2.16 (IO18), U3.4 (!RST)
RX: TP2.TP, U2.24 (RXD0/GPIO17)
SCK: D10.1, J1.13, J4.P5 (CLK), R6.1, TP8.TP, U1.6 (CLK), U2.6 (IO6)
SCL: J3.4, R2-PINH.1, SENSOR2.4 (SCK), U2.20 (IO22), U3.16 (SCL), U4.7 (SCL)
SDA: J3.3, R1_PINH.1, SENSOR2.3 (SDI), U2.19 (IO21), U3.15 (SDA), U4.8 (SDA)
SRC: C4.2, D5.2 (A), L1.1, Q3.3 (D)
SS_SD: D8.1, J4.P2 (CD/DAT3), R10.1, U2.4 (IO4)
TX: TP1.TP, U2.25 (TXD0/GPIO16)
USB_D+: D1.1 (I/O1_1), U2.14 (IO13)
USB_D-: D1.3 (I/O2_1), U2.13 (IO12)
VBAT: C2_BAT.1, MCP73831.3 (VBAT), Q1.3 (D), TP3.TP, U4.2 (CELL), U4.3 (VDD)
VBUS: C1_BAT.1, C4_USB.1, C5_USB.1, CHG_LED.A, D1.5 (VBUS), D2.2 (ANODE), MCP73831.4 (VIN), PFMF.050.1.2, Q1.1 (G), R1_PWRUSB.2, TP14.TP
VRTC: C8.1, C10_SUPERCAP.2, R_CAPACITOR.1, U3.14 (VBAT)
VUSB: J2.A4, J2.A9, J2.B4, J2.B9, PFMF.050.1.1

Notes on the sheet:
USB C connector & ESD protection
LDO Voltage Regulator
DMG2305UX-7
SD0805S020S1R0
SD Card
ESP32 C6
Li-Po Battery Charging Controller
E-Paper Drive Circuit
68uH
Display Type Selector
Battery Charge Level
Voltage Supervisor + Reset & Boot / IO Button
CHANGE_BUTTON
BOOT_BUTTON
RESET_BUTTON
Environmental Sensor BME688
BME688
EPD Power
E-Paper Display Header
RTC Module DS3231SN
Test Pads
Qwiic / Stemma QT
OpenBook Schematic
SPI ESD Protection Lines
External NOR Flash 64MB
drawn by: Duta Vicentiu-Alecsandru

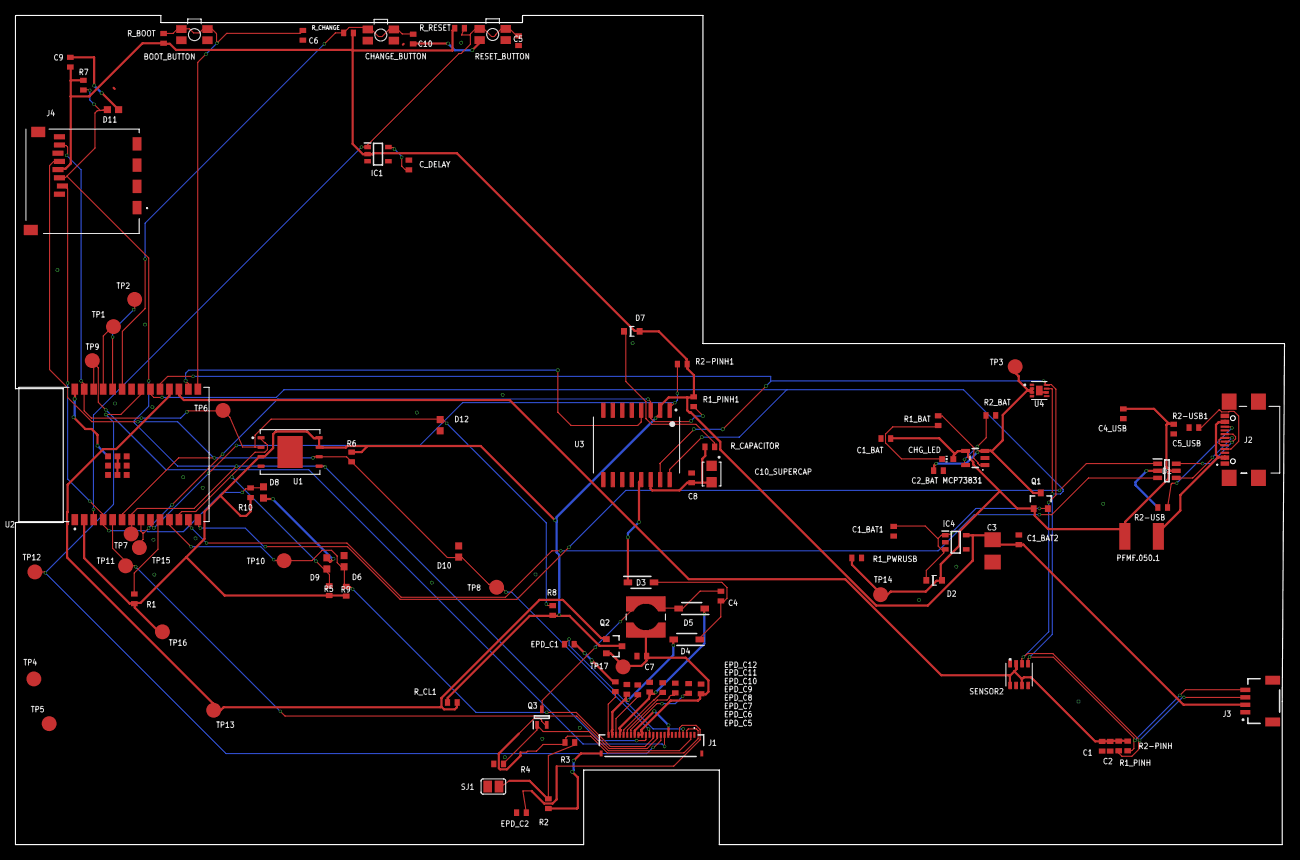
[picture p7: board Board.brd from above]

Board: 2 copper layers, 170.2 x 111.2 mm, 103 parts (0 on the bottom side), 55 nets.

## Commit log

2025-04-05 Create exploded view.step
    [exploded view.step]
2025-04-10 Remaining exploded view and manufacturing
    [Board.brd, Schematic.sch]
2025-04-14 FInal version of files. Remaining gerbers
    [Board.brd, Schematic.sch]
2025-04-14 added gerbers.zip

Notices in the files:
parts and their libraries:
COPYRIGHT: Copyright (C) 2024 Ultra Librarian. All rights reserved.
